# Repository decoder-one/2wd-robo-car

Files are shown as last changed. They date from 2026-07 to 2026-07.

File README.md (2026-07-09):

# 2wd-robo-car
2 dc motors, arduino uno with shield 5.0, L298N dual full-bridge driver , servo and ultrasonic sensor

complete set:
https://www.roboter-bausatz.de/p/bausatz-2wd-roboter-smart-car-arduino-kit
other kits see www

parts:
UNO R3 board,
2 wheels with tires,
2 gear motors,
4 motor cables,
Acrylic chassis,
Motor driver,
Ultrasonic sensor with mount,
Servo motor,
Battery holder,
USB cable,
Assorted screws and nuts for assembly

!!! It is necessary to use two 18650 batteries for the power supply.

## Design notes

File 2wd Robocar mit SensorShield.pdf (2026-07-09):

### 2wd Robocar mit SensorShield, Motorsteuerung, Servo und Ultraschallsensor

Wichtige Vorbereitung
Der "5V-Enable"-Jumper auf dem L298N-Modul muss aufgesteckt bleiben! Das Sensor Shield V5.0 wird fest auf den Arduino Uno gesteckt.

Der komplette Verkabelungsplan

### 1. Stromversorgung (Akkuhalter 2x 3,7V Li-Ion Akkus 18650er & L298N Klemmen)

Akkuhalter Plus (+) → an 12V Klemme des L298N
Akkuhalter Minus (-) → an GND Klemme des L298N

### 2. Strombrücke zum Arduino (über das Sensor Shield)

Vom L298N zweigen wir jetzt den Strom ab, um den Arduino und das Sensor Shield zu füttern: GND Klemme des L298N → an einen beliebigen GND-Pin (schwarz) auf dem Sensor Shield
5V Klemme des L298N → an einen beliebigen 5V-Pin (rot) auf dem Sensor Shield

### 3. Die beiden Antriebsmotoren (2WD)

Motor Links: Die beiden Kabel kommen in die Schraubklemmen OUT1 und OUT2 des L298N. Motor Rechts: Die beiden Kabel kommen in die Schraubklemmen OUT3 und OUT4 des L298N.

### 4. Steuerung: Arduino zu L298N (Logik-Pins)

Entferne die vier Jumper-Kappen von den Pins IN1, IN2, IN3, IN4 am L298N. Verbinde sie mit den digitalen Pins (Reihe S / Signal) des Sensor Shields:

IN1 → Pin 5 (Sensor Shield)
IN2 → Pin 6 (Sensor Shield)
IN3 → Pin 9 (Sensor Shield)
IN4 → Pin 10 (Sensor Shield)
(Hinweis: Die Pins 5, 6, 9 und 10 unterstützen PWM, falls du später die Geschwindigkeit der Motoren regeln willst).

### 5. Ultraschallsensor (HC-SR04)

Das Sensor Shield V5.0 hat oft einen extra Bereich für "URF" (Ultrasonic), du kannst aber auch jede normale Pin-Reihe nutzen. Wir nehmen hier beispielhaft Pin 11 und 12:

VCC → an einen 5V-Pin (rot) bei Pin 11 oder 12
GND → an einen GND-Pin (schwarz) bei Pin 11 oder 12
Trig → an Signal-Pin 11 (blau/gelb)
Echo → an Signal-Pin 12 (blau/gelb)

### 6. Servomotor (SG90 o.ä.)

Servos haben meistens ein dreipoliges Kabel (Braun/Schwarz = GND, Rot = VCC, Orange/Gelb = Signal). Das steckst du direkt auf die dreifach-Pins des Sensor Shields (z. B. auf Pin 3):

Braun/Schwarz → an GND (schwarz) bei Pin 3
Rot → an 5V (rot) bei Pin 3
Orange/Gelb → an Signal-Pin 3 (blau/gelb)

Wichtige Hinweise zum ersten Testlauf:
Richtung der Motoren prüfen: Es kann gut sein, dass sich beim ersten Testen ein Rad rückwärts dreht, obwohl das Auto "vorwärts" fahren soll. Tausche in diesem Fall einfach die beiden Kabel des betroffenen Motors in der Schraubklemme des L298N.

Drehzeiten anpassen: In den Funktionen für dreheLinks() und dreheRechts() steht im loop ein delay(500);. Je nachdem, wie schnell deine Motoren mit den 7,4V-Akkus drehen und wie griffig der Untergrund ist, dreht sich das Auto in dieser halben Sekunde mehr oder weniger weit. Den Wert kannst du anpassen, bis das Auto eine schöne 90-Grad-Kurve macht.

Denk beim Aufspielen des Codes per USB-Kabel daran: Trenne kurz das Kabel, das von der 5V-Klemme des L298N zum Sensor Shield führt. Sobald der Code drauf ist, USB abziehen, Kabel wieder rein, Schalter an den Akkus an – und dein 2WD-Flitzer legt los!

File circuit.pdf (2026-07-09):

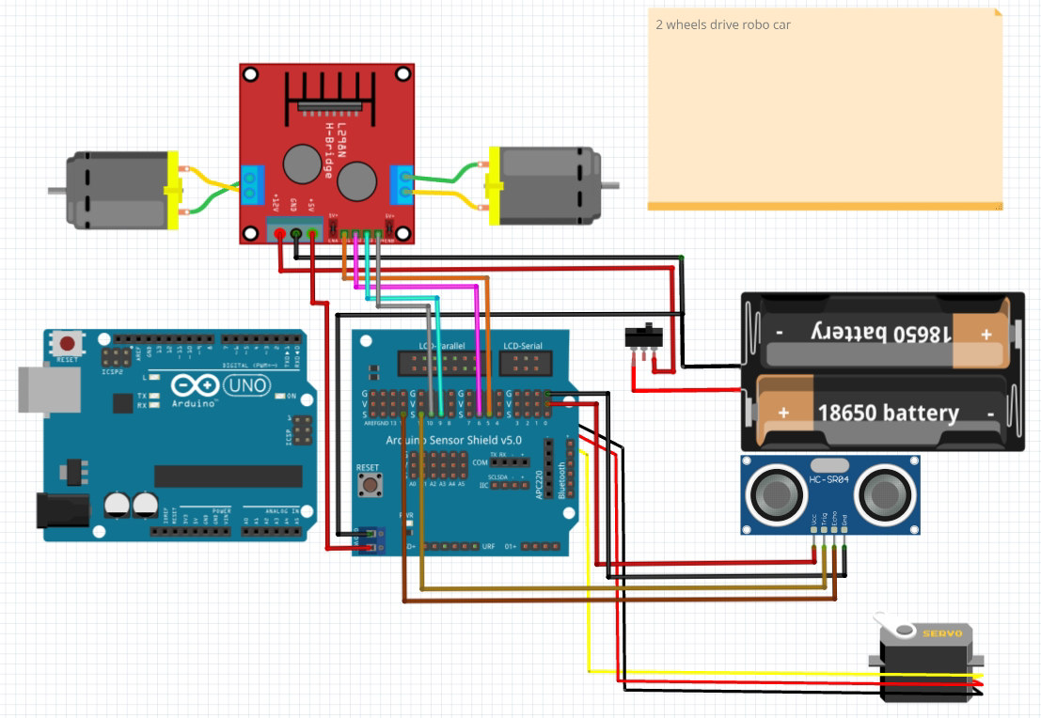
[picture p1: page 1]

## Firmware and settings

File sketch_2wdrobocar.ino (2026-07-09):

#include <Servo.h>

// Pins für das L298N Motor Shield
const int IN1 = 5;
const int IN2 = 6;
const int IN3 = 9;
const int IN4 = 10;

// --- PWM GESCHWINDIGKEITEN FÜR GERADEAUSLAUF ---
// Passe diese beiden Werte an, bis der Roboter geradeaus fährt!
const int SPEED_LINKS = 180;  // Geschwindigkeit linker Motor (IN1/IN2)
const int SPEED_RECHTS = 195; // Geschwindigkeit rechter Motor (IN3/IN4)

// Pins für den HC-SR04 Ultraschallsensor
const int TRIG_PIN = 11;
const int ECHO_PIN = 12;

// Pin und Objekt für den Servo
const int SERVO_PIN = 3;
Servo meinServo;

// Variablen für die Distanzmessung
long dauer;
int distanz;
int distanzRechts;
int distanzLinks;

void setup() {
  // Motor-Pins als Ausgänge definieren
  pinMode(IN1, OUTPUT);
  pinMode(IN2, OUTPUT);
  pinMode(IN3, OUTPUT);
  pinMode(IN4, OUTPUT);

  // Sensor-Pins definieren
  pinMode(TRIG_PIN, OUTPUT);
  pinMode(ECHO_PIN, INPUT);

  // Servo initialisieren und nach vorne ausrichten (90 Grad)
  meinServo.attach(SERVO_PIN);
  meinServo.write(90);
  delay(500);
}

void loop() {
  distanz = messeDistanz();

  if (distanz > 20) {
    vorwaerts();
  } 
  else {
    stopp();
    delay(200);
    rueckwaerts();
    delay(300);
    stopp();
    delay(200);

    umgebungScannen();

    if (distanzRechts >= distanzLinks) {
      dreheRechts();
      delay(200);
    } else {
      dreheLinks();
      delay(200);
    }
    stopp();
    delay(200);
  }
  delay(50);
}

int messeDistanz() {
  digitalWrite(TRIG_PIN, LOW);
  delayMicroseconds(2);
  digitalWrite(TRIG_PIN, HIGH);
  delayMicroseconds(10);
  digitalWrite(TRIG_PIN, LOW);
  
  dauer = pulseIn(ECHO_PIN, HIGH);
  int cm = dauer * 0.034 / 2;
  
  if (cm == 0) cm = 250;
  return cm;
}

void umgebungScannen() {
  meinServo.write(20);
  delay(500);
  distanzRechts = messeDistanz();
  
  meinServo.write(160);
  delay(500);
  distanzLinks = messeDistanz();
  
  meinServo.write(90);
  delay(500);
}

// --- Bewegungsfunktionen mit getrennter PWM-Steuerung ---

void vorwaerts() {
  analogWrite(IN1, SPEED_LINKS);
  analogWrite(IN2, 0);
  analogWrite(IN3, SPEED_RECHTS);
  analogWrite(IN4, 0);
}

void rueckwaerts() {
  analogWrite(IN1, 0);
  analogWrite(IN2, SPEED_LINKS);
  analogWrite(IN3, 0);
  analogWrite(IN4, SPEED_RECHTS);
}

void dreheLinks() {
  // Beim Drehen auf der Stelle nutzen wir die jeweiligen Werte
  analogWrite(IN1, 0);
  analogWrite(IN2, SPEED_LINKS);
  analogWrite(IN3, SPEED_RECHTS);
  analogWrite(IN4, 0);
}

void dreheRechts() {
  analogWrite(IN1, SPEED_LINKS);
  analogWrite(IN2, 0);
  analogWrite(IN3, 0);
  analogWrite(IN4, SPEED_RECHTS);
}

void stopp() {
  analogWrite(IN1, 0);
  analogWrite(IN2, 0);
  analogWrite(IN3, 0);
  analogWrite(IN4, 0);
}

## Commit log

2026-07-08 Update motor description in README.md
2026-07-09 Fritzing file
    [2wd_robocar.fzz]
2026-07-09 Update README with parts list and power supply details
    Added detailed parts list and power supply information.
2026-07-09 circuit for fritzing
2026-07-09 Refactor motor control to use PWM for speed
